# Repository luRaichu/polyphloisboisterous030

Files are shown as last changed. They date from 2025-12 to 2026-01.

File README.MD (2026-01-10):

# Polyphloisboisterous '030

This is my 16 MHz 68030 microprocessor upgrade board for Apple's Macintosh Plus, derived from the [reverse-engineered](https://github.com/alxlab-zone66x/Performer-SE-PL-CL/tree/main) MicroMac Performer. It is designed for easy and low-cost assembly by hobbyists.

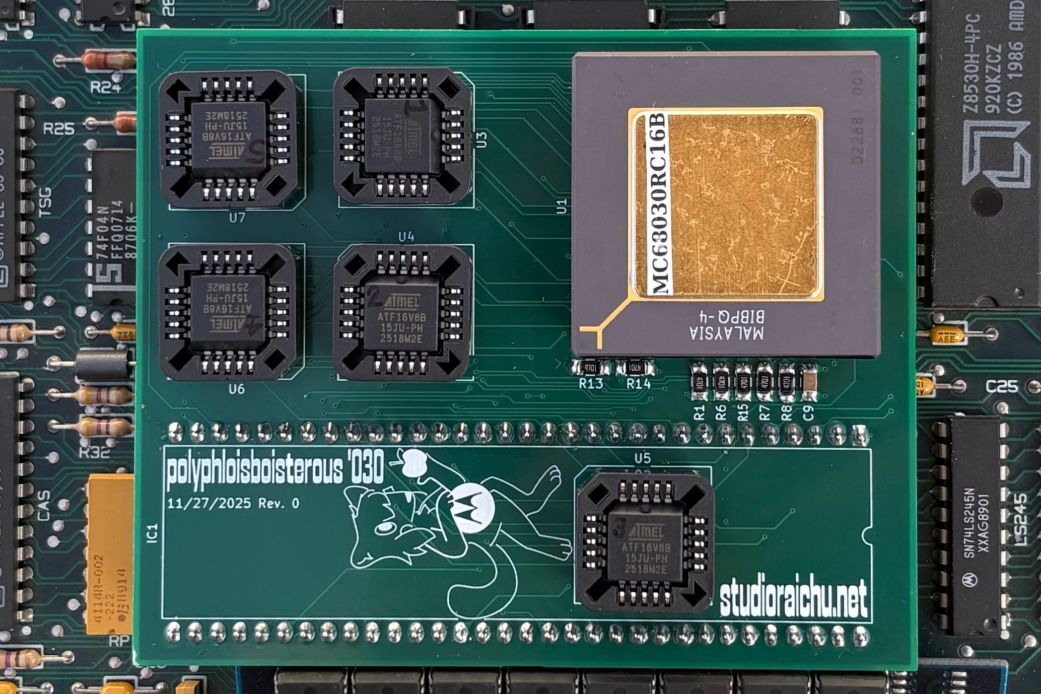
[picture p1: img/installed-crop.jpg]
Photo of Polyphloisboisterous '030 installed in Macintosh Plus


I created it because I didn't want to pay the relatively high manufacturing costs to get five Performer clone boards made, and I would have a hard time surface mount soldering the GALs.

My board is 50% smaller and 77% cheaper to manufacture over the original Performer, and doesn't use any dense SMD footprints. It can be assembled by anyone who can recap a vintage computer motherboard.

The provided PCB files are licensed under CC BY-NC-SA - they're NOT intended for commercial use.

## Notes on GALs

The original Performer GALs have been dumped. GAL16V8-15, PALCE16V8-15, and ATF16V8-15 have been tested as suitable replacements.

I used ATF16V8B-15JU, they are in stock at DigiKey and Mouser.

Faster/slower chips haven't been tested so far.

I used [afterburner](https://github.com/ole00/afterburner) to program GALs cheaply.

## Why is the FPU missing?

Because it's seldomly used on the Macintosh, and the PCB layout is simpler without it. There's not much point in having super fast floating point math when very little software uses it and if it'll be bottlenecked by the 16 MHz CPU and 16-bit data bus.

## Bill of Materials

|Quantity|Description|Designators|
|---|---|---|
|16|4.7 kΩ resistor, 1/4W or better, 1206 package|R1, R2, R3, R4, R5, R6, R7, R8, R9, R10, R11, R12, R13, R14, R15, R16|
|6|0.1μF ceramic capacitor, 6.3V or better, 1206 package|C4, C5, C6, C7, C8, C9|
|2|22μF tantalum capacitor, 10V or better, 2312 package|C1, C3|
|5|20 (4 x 5) pos. PLCC socket, through hole|U3, U4, U5, U6, U7|
|5|16V8 GALs or PALs, ATF16V8 recommended|U3, U4, U5, U6, U7|
|1|**Optional:** PGA-128 socket or equivalent for 68030. I used discrete machined pin headers|U1|
|1|MC68030, PGA, at least 16 MHz|U1|
||Headers and sockets to stack Polyphloisboisterous '030 on top of 68000. I used two 32 pos. round pin headers with a 64 (2 x 32) pos. machined pin DIP socket|IC1|

## Revision History
* 11/27/2025 Rev. 0 - First version
* 12/26/2025 Rev. 1 - Made board slightly shorter to help clear top of SIMM 1

## Assembly
1. Solder passives (resistors, capacitors) to board.

2. Solder GAL sockets to board.

3. Either solder PGA socket to board or permanently solder 68030 directly to board. In my case, I pushed individual pin headers onto the 68030 before soldering it. See [this graphic](img/cpuheaders-diagram.png) for my placement of these headers.

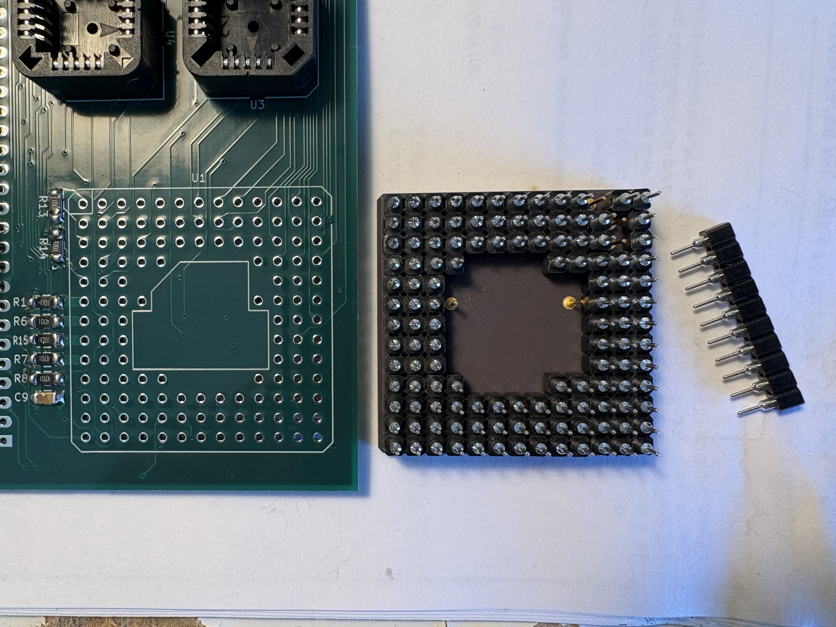
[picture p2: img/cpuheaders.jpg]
Photo of pin headers seated on 68030 pins


4. Solder 68000 piggyback connector(s) (i.e. male pin headers) to board.

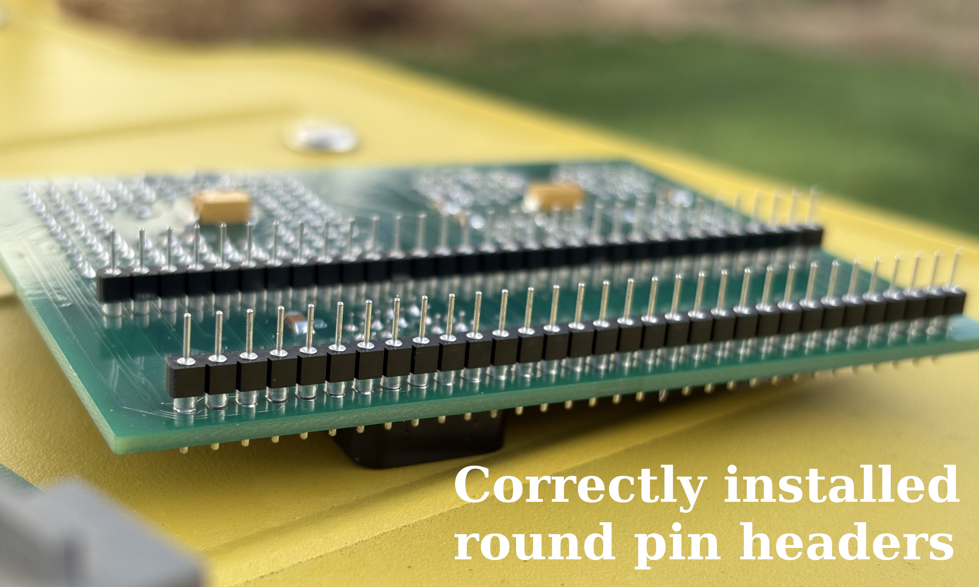
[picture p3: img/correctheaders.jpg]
Photo of correctly soldered male round pin headers


5. Program GALs and insert into sockets.

Your board should look like this:

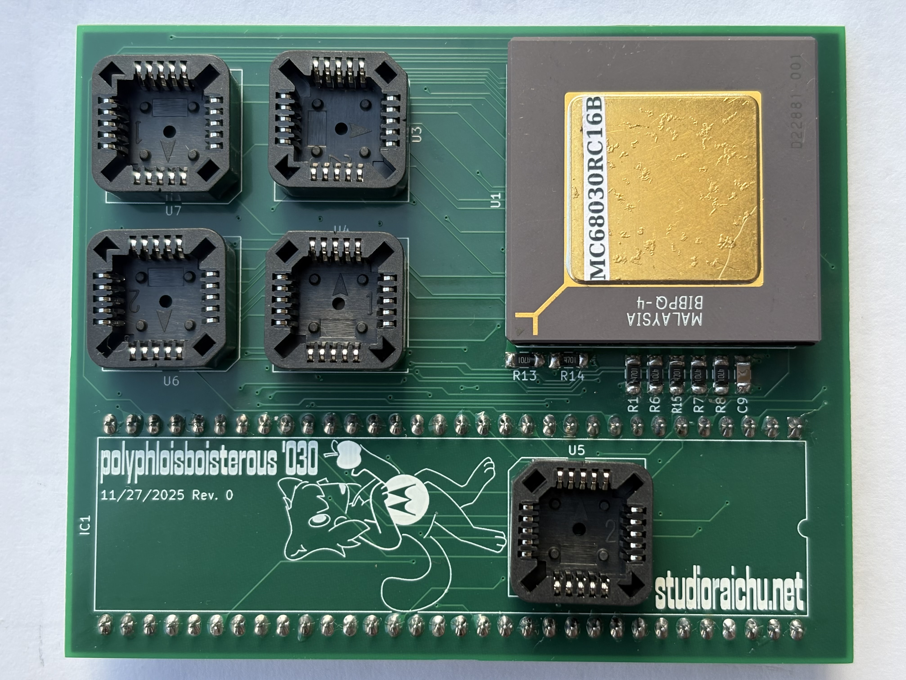
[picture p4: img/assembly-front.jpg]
Photo of assembled Polyphloisboisterous '030, front view


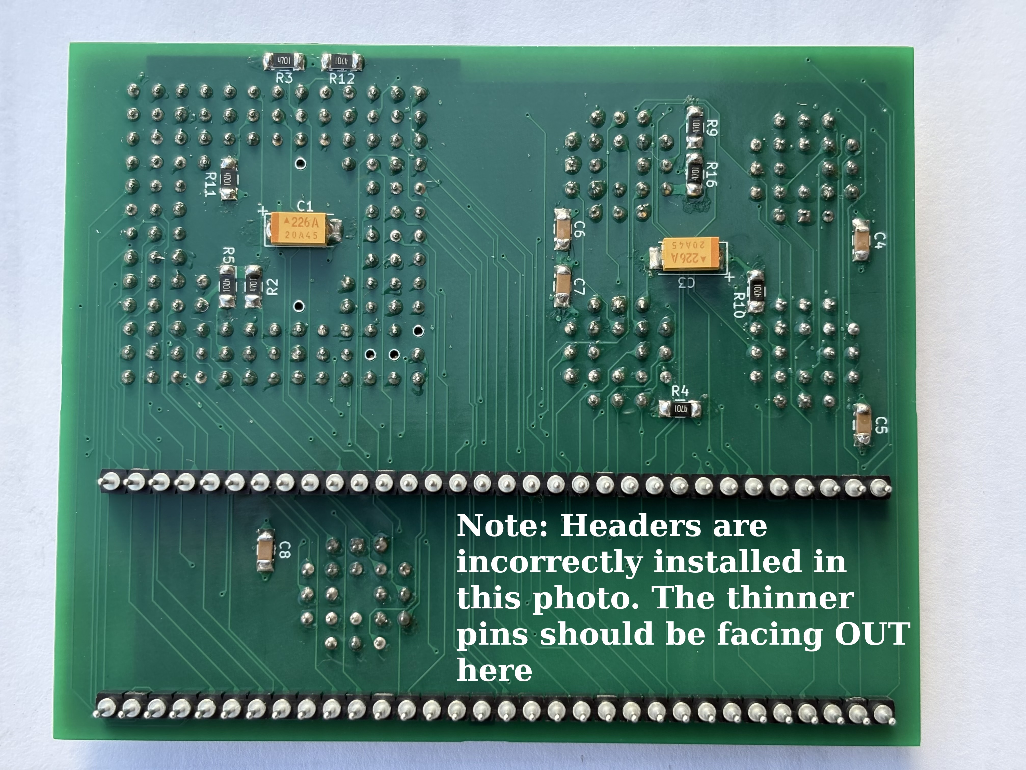
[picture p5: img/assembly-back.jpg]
Photo of assembled Polyphloisboisterous '030, back view


## Installation
1. Solder piggyback connector (i.e. female machined pin DIP socket) on top of the 68000 microprocessor on the Macintosh Plus logic board.

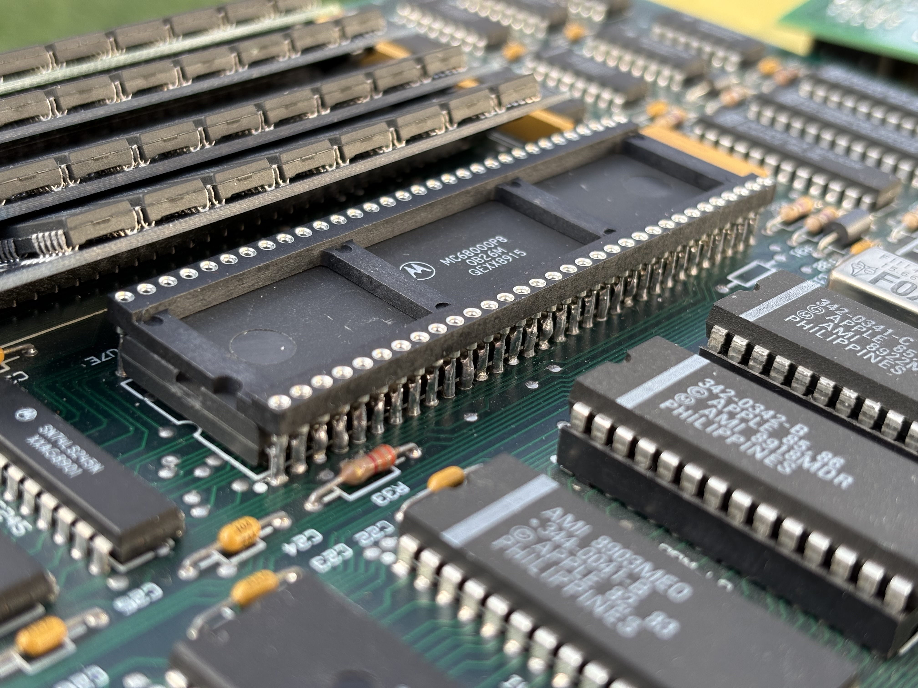
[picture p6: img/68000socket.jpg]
Photo of female machined pin DIP socket soldered on top of 68000


2. Seat the Polyphloisboisterous '030 accelerator on top of the 68000. It should look as pictured. Be mindful of the top of SIMM 1.

Photo of Polyphloisboisterous '030 installed on Macintosh Plus logic board, top view

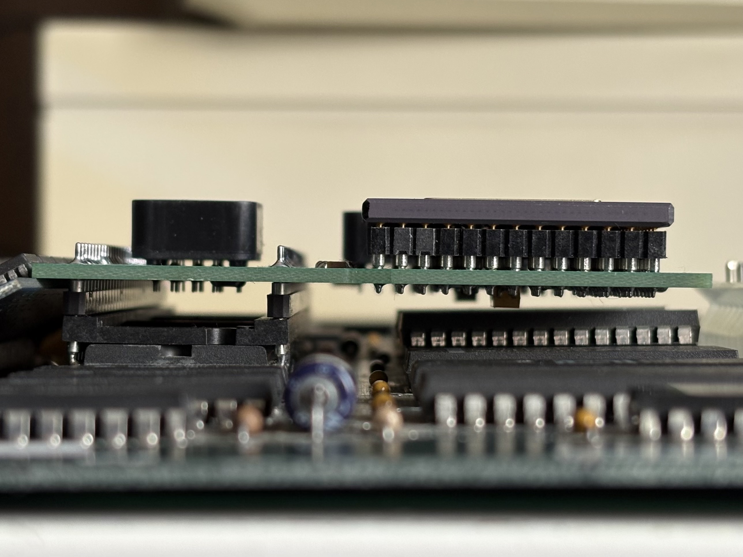
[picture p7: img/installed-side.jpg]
Photo of Polyphloisboisterous '030 installed on Macintosh Plus logic board, side view


3. Make a test: Have the logic board next to the Mac and connect the multicolored wire harness. Make sure that the logic board or accelerator do not touch any metal part of the chassis. Turn power on and listen for the beep. If you get a beep the accelerator is working. Turn power off and continue with the installation.

4. Carefully slide the logic board back into position while watching the accelerator **or** alternatively slide it **underneath** the rails and into the chassis, then slot the logic board into a rail on one side and bend the chassis on the other side in such a way that the logic board does go into the other rail as well.

5. Download the correct version of the [GemStart Universal](https://macintoshgarden.org/apps/accelerator-card-drivers) driver for your System Software. You will need:

    * GemStart 2.2 for System 6
    * GemStart 3.0 for System 7.0 (not recommended)
    * GemStart 7.1 for System 7.1

    If asked, identify your accelerator as a "Total Systems Mercury" in the installer (it is logically identical to this one). GemStart should show that you have a 16 MHz 68030.

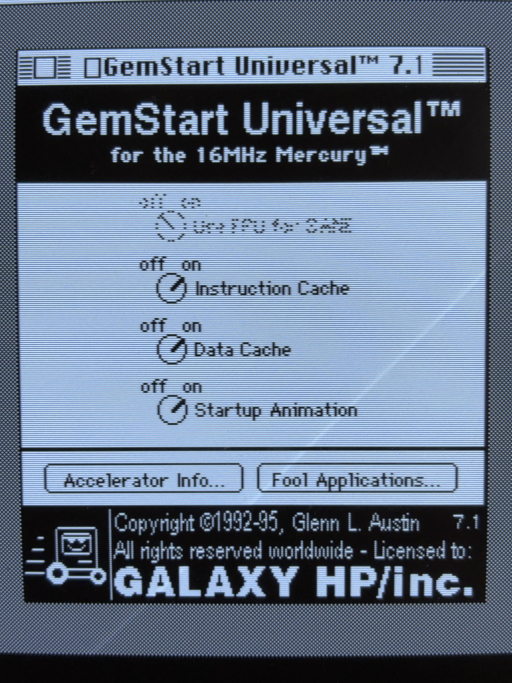
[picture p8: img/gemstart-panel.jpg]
Photo of GemStart control panel on screen


## Performance

I tested System 6.0.8 and 7.1 with this accelerator, both booted from my external BlueSCSI disk emulator.

Here are the benchmark results from Speedometer 3.23:

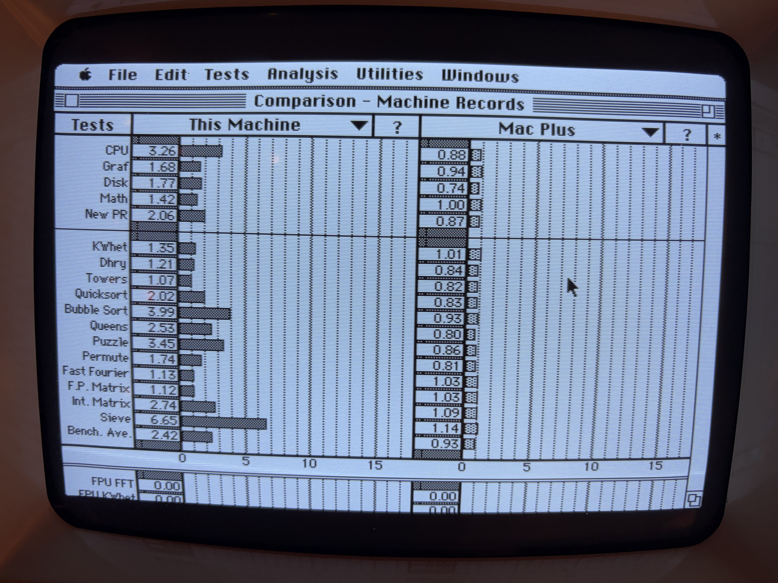
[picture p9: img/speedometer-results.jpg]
Photo of Speedometer 3.23 benchmark results on screen


To temporarily disable the Polyphloisboisterous '030 (and similar upgrades) using the Programmer's Switch, hold Interrupt after the boot chime then quickly press Reset. After the second chime release Interrupt. The upgrade is disabled until the next boot.

It appears that these accelerators affect the Macintosh's Sound Manager. Audio playback may be garbled or cut in and out rapidly. I don't know why.

## Thanks
To Bolle and Trash80toHP_Mini of 68kMLA forums, for reverse engineering the Mercury 030 and MicroMac Performer.

To alxlab-zone66x, for converting the Performer EAGLE files to a KiCad project.



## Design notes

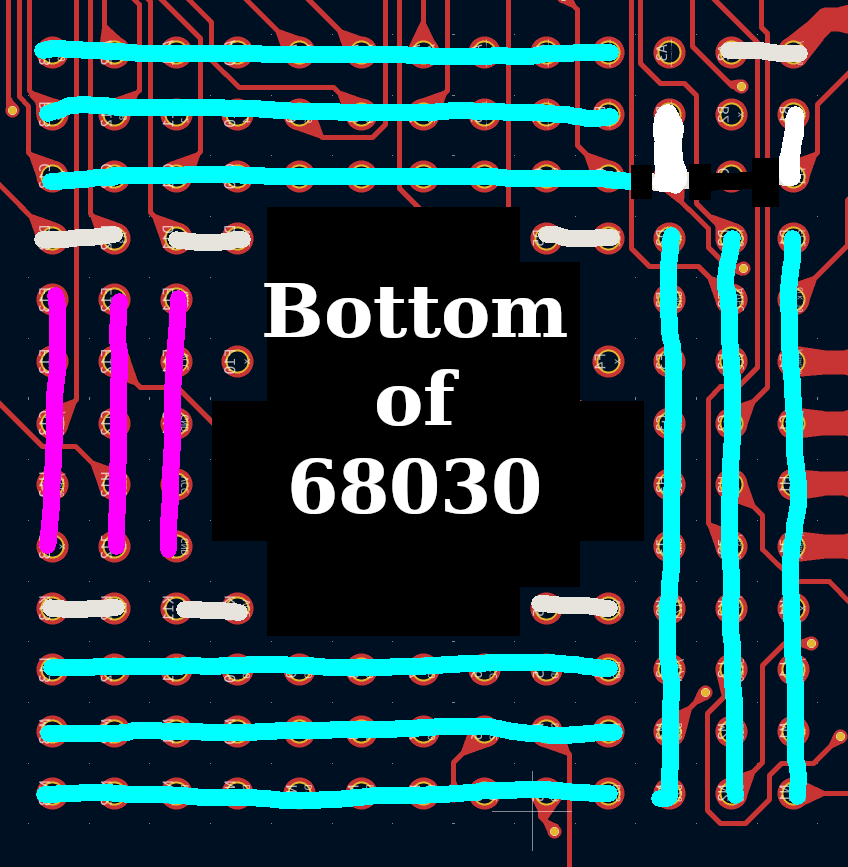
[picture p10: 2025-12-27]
img/cpuheaders-diagram.png

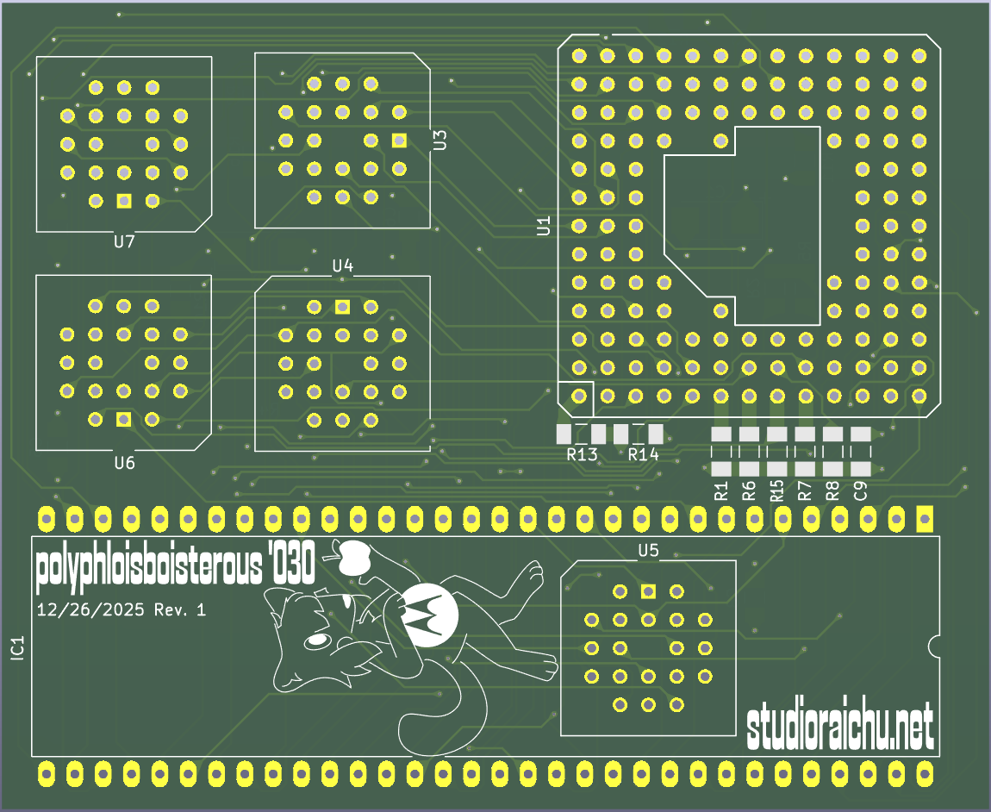
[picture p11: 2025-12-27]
kicad/polyphloisboisterous030-1.png

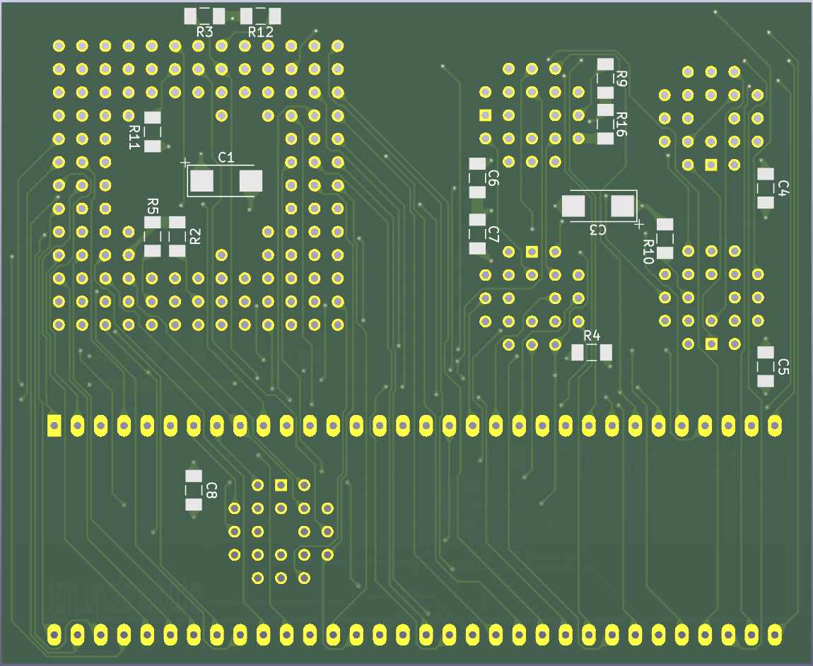
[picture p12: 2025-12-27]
kicad/polyphloisboisterous030-2.png

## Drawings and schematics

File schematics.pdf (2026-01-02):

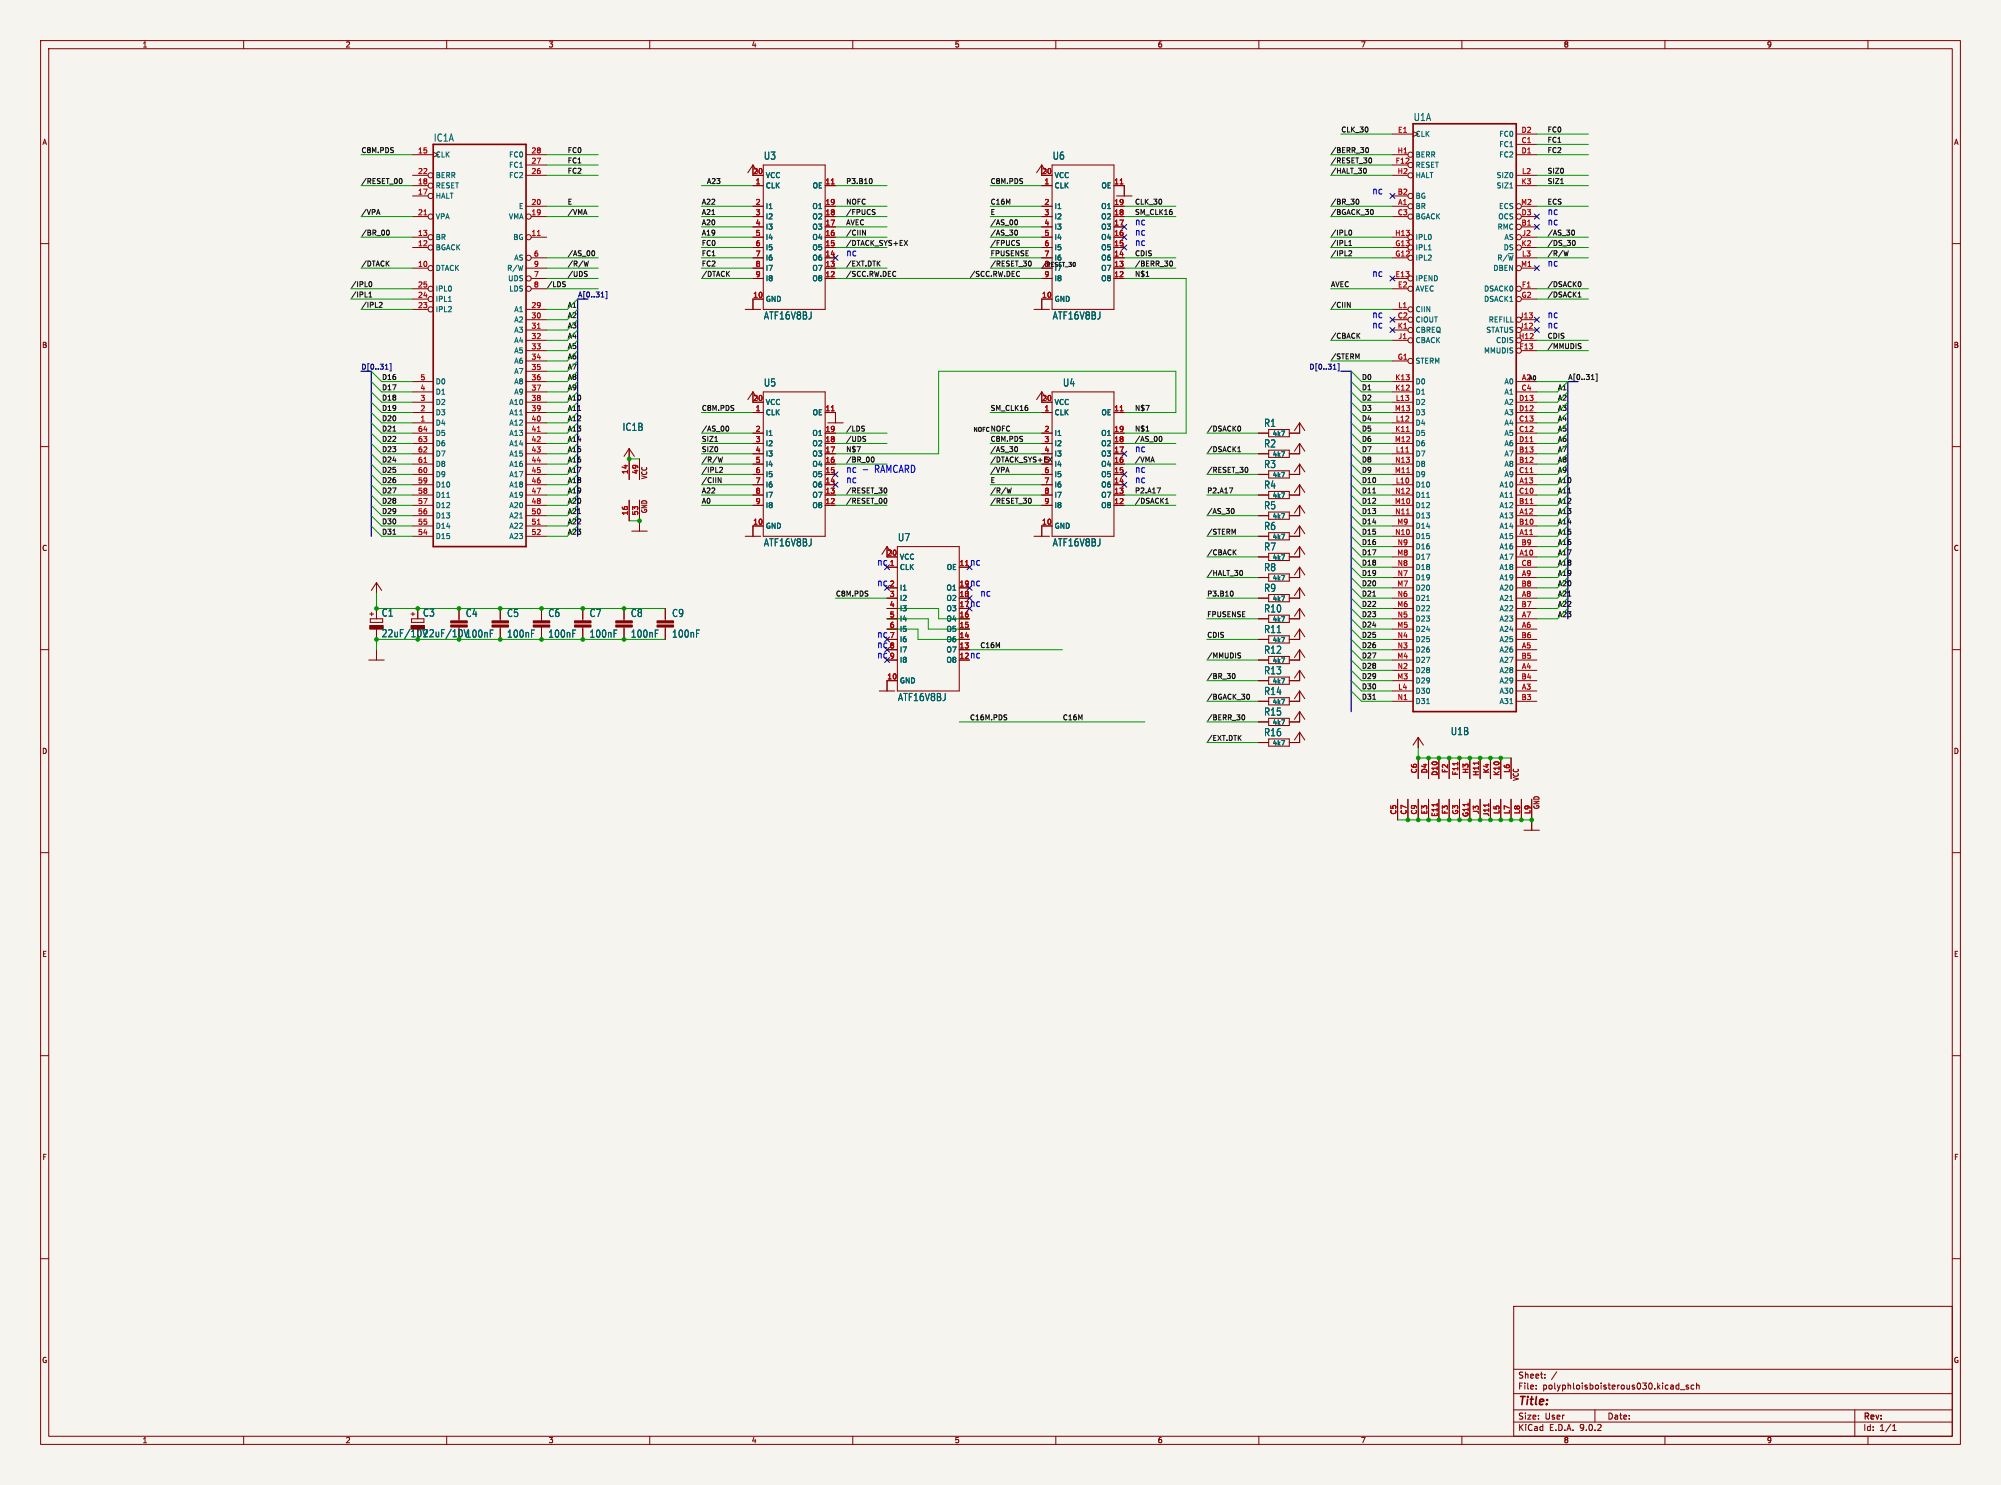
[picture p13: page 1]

CLK E1 BERR H1 RESET F12 HALT H2 BG B2 BR A1 BGACK C3
SIZ0 D31

IPEND E13 AVEC E2 CIIN L1 CIOUT C2 CBREQ K1 CBACK J1 STERM G1 D0 K13 D1 K12 D2 L13 D3 M13 D4 L12 D5 K11 D6 M12 D7 L11 D8 N13 D9 M11 D10 L10 D11 N12 D12 M10 D13 N11 D14 M9 D15 N10 D16 N9 D17 M8 D18 N8 D19 N7 D20 M7 D21 N6 D22 M6 D23 N5 D24 M5 D25 N4 D26 N3 D27 M4 D28 N2 D29 M3 D30 L4 D31 N1

Id: 1/1 Title: File: polyphloisboisterous030.kicad_sch Sheet: /

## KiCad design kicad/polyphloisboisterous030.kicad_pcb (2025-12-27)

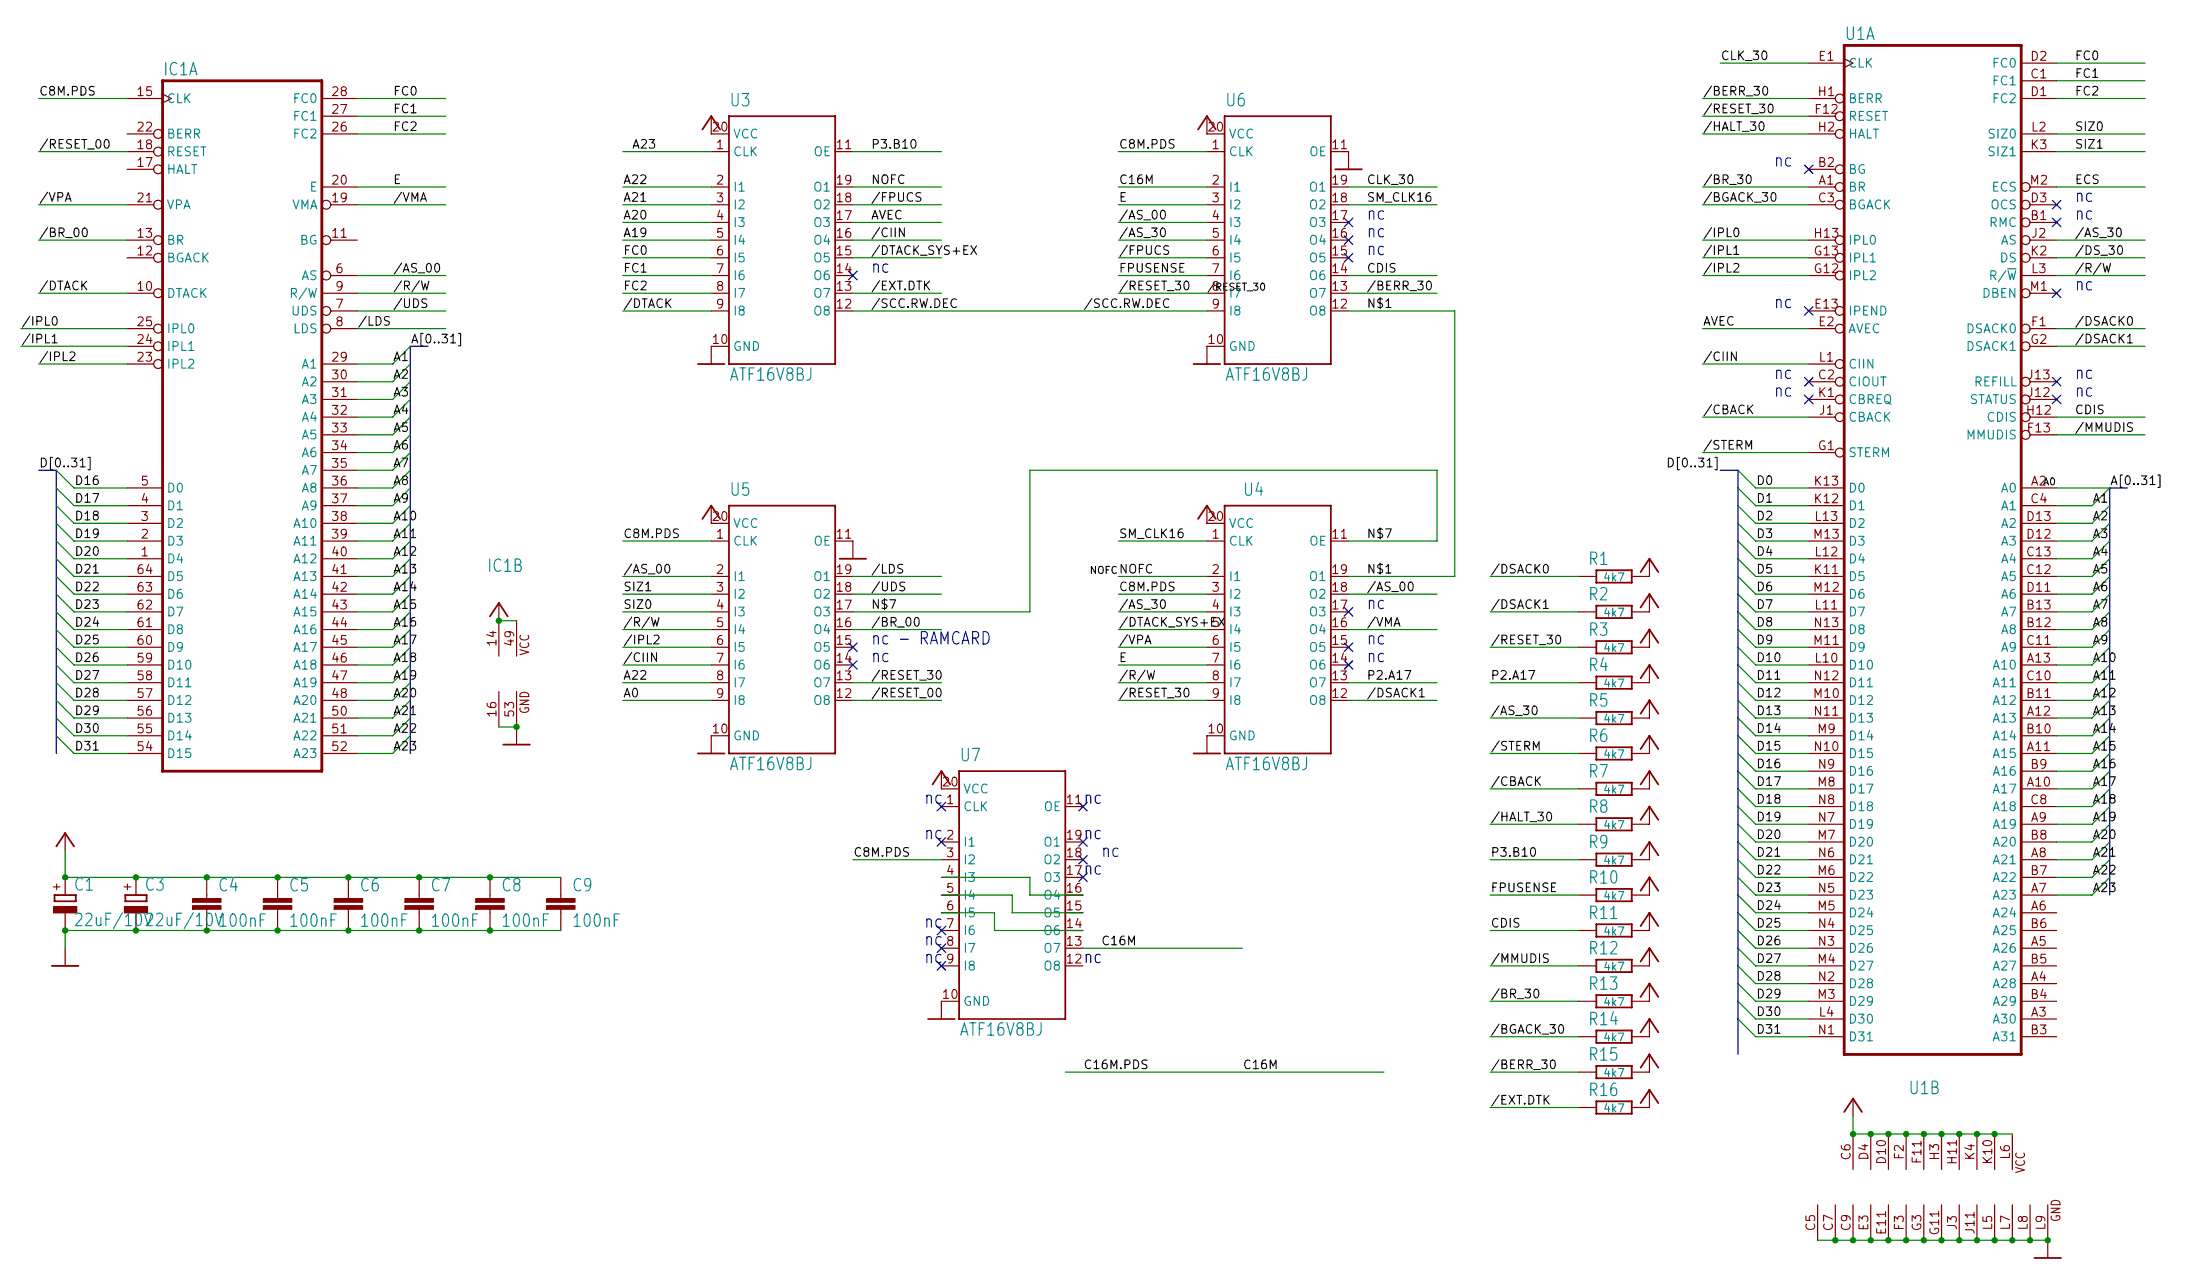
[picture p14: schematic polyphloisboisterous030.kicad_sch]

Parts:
C1, C3: 22uF/10V; CP_EIA-6032-15_Kemet-U_Pad2.25x2.35mm_HandSolder
C4, C5, C6, C7, C8, C9: 100nF; C_1206_3216Metric_Pad1.60x1.80mm_HandSolder
IC1: MC68000P; DIP-64_W22.86mm_LongPads_Mirror
R1, R2, R3, R4, R5, R6, R7, R8, R9, R10, R11, R12, R13, R14, R15, R16: 4k7; R_1206_3216Metric_Pad1.60x1.80mm_HandSolder
U1: MC68030RC; CPGA-128_Layout13x13_MC68030
U3, U4, U5, U6, U7: ATF16V8BJ; PLCC-20_THT-Socket

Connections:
/A0: U1.A2 (A0), U5.9 (I8)
/A1: IC1.29 (A1), U1.C4 (A1)
/A2: IC1.30 (A2), U1.D13 (A2)
/A3: IC1.31 (A3), U1.D12 (A3)
/A4: IC1.32 (A4), U1.C13 (A4)
/A5: IC1.33 (A5), U1.C12 (A5)
/A6: IC1.34 (A6), U1.D11 (A6)
/A7: IC1.35 (A7), U1.B13 (A7)
/A8: IC1.36 (A8), U1.B12 (A8)
/A9: IC1.37 (A9), U1.C11 (A9)
/A10: IC1.38 (A10), U1.A13 (A10)
/A11: IC1.39 (A11), U1.C10 (A11)
/A12: IC1.40 (A12), U1.B11 (A12)
/A13: IC1.41 (A13), U1.A12 (A13)
/A14: IC1.42 (A14), U1.B10 (A14)
/A15: IC1.43 (A15), U1.A11 (A15)
/A16: IC1.44 (A16), U1.B9 (A16)
/A17: IC1.45 (A17), U1.A10 (A17)
/A18: IC1.46 (A18), U1.C8 (A18)
/A19: IC1.47 (A19), U1.A9 (A19), U3.5 (I4)
/A20: IC1.48 (A20), U1.B8 (A20), U3.4 (I3)
/A21: IC1.50 (A21), U1.A8 (A21), U3.3 (I2)
/A22: IC1.51 (A22), U1.B7 (A22), U3.2 (I1), U5.8 (I7)
/A23: IC1.52 (A23), U1.A7 (A23), U3.1 (CLK)
/AVEC: U1.E2 (AVEC), U3.17 (O3)
/C8M.PDS: IC1.15 (CLK), U4.3 (I2), U5.1 (CLK), U6.1 (CLK), U7.3 (I2)
/C16M: U6.2 (I1), U7.13 (O7)
/CDIS: R11.1, U1.H12 (CDIS), U6.14 (O6)
/CLK_30: U1.E1 (CLK), U6.19 (O1)
/D0: U1.K13 (D0)
/D1: U1.K12 (D1)
/D2: U1.L13 (D2)
/D3: U1.M13 (D3)
/D4: U1.L12 (D4)
/D5: U1.K11 (D5)
/D6: U1.M12 (D6)
/D7: U1.L11 (D7)
/D8: U1.N13 (D8)
/D9: U1.M11 (D9)
/D10: U1.L10 (D10)
/D11: U1.N12 (D11)
/D12: U1.M10 (D12)
/D13: U1.N11 (D13)
/D14: U1.M9 (D14)
/D15: U1.N10 (D15)
/D16: IC1.5 (D0), U1.N9 (D16)
/D17: IC1.4 (D1), U1.M8 (D17)
/D18: IC1.3 (D2), U1.N8 (D18)
/D19: IC1.2 (D3), U1.N7 (D19)
/D20: IC1.1 (D4), U1.M7 (D20)
/D21: IC1.64 (D5), U1.N6 (D21)
/D22: IC1.63 (D6), U1.M6 (D22)
/D23: IC1.62 (D7), U1.N5 (D23)
/D24: IC1.61 (D8), U1.M5 (D24)
/D25: IC1.60 (D9), U1.N4 (D25)
/D26: IC1.59 (D10), U1.N3 (D26)
/D27: IC1.58 (D11), U1.M4 (D27)
/D28: IC1.57 (D12), U1.N2 (D28)
/D29: IC1.56 (D13), U1.M3 (D29)
/D30: IC1.55 (D14), U1.L4 (D30)
/D31: IC1.54 (D15), U1.N1 (D31)
/E: IC1.20 (E), U4.7 (I6), U6.3 (I2)
/ECS: U1.M2 (ECS)
/FC0: IC1.28 (FC0), U1.D2 (FC0), U3.6 (I5)
/FC1: IC1.27 (FC1), U1.C1 (FC1), U3.7 (I6)
/FC2: IC1.26 (FC2), U1.D1 (FC2), U3.8 (I7)
/FPUSENSE: R10.1, U6.7 (I6)
/N$1: U4.19 (O1), U6.12 (O8)
/N$7: U4.11 (OE), U5.17 (O3)
/NOFC: U3.19 (O1), U4.2 (I1)
/P2.A17: R4.1, U4.13 (O7)
/P3.B10: R9.1, U3.11 (OE)
/SIZ0: U1.L2 (SIZ0), U5.4 (I3)
/SIZ1: U1.K3 (SIZ1), U5.3 (I2)
/SM_CLK16: U4.1 (CLK), U6.18 (O2)
//AS_00: IC1.6 (AS), U4.18 (O2), U5.2 (I1), U6.4 (I3)
//AS_30: R5.1, U1.J2 (AS), U4.4 (I3), U6.5 (I4)
//BERR_30: R15.1, U1.H1 (BERR), U6.13 (O7)
//BGACK_30: R14.1, U1.C3 (BGACK)
//BR_00: IC1.13 (BR), U5.16 (O4)
//BR_30: R13.1, U1.A1 (BR)
//CBACK: R7.1, U1.J1 (CBACK)
//CIIN: U1.L1 (CIIN), U3.16 (O4), U5.7 (I6)
//DSACK0: R1.1, U1.F1 (DSACK0)
//DSACK1: R2.1, U1.G2 (DSACK1), U4.12 (O8)
//DS_30: U1.K2 (DS)
//DTACK: IC1.10 (DTACK), U3.9 (I8)
//DTACK_SYS+EX: U3.15 (O5), U4.5 (I4)
//EXT.DTK: R16.1, U3.13 (O7)
//FPUCS: U3.18 (O2), U6.6 (I5)
//HALT_30: R8.1, U1.H2 (HALT)
//IPL0: IC1.25 (IPL0), U1.H13 (IPL0)
//IPL1: IC1.24 (IPL1), U1.G13 (IPL1)
//IPL2: IC1.23 (IPL2), U1.G12 (IPL2), U5.6 (I5)
//LDS: IC1.8 (LDS), U5.19 (O1)
//MMUDIS: R12.1, U1.F13 (MMUDIS)
//RESET_00: IC1.18 (RESET), U5.12 (O8)
//RESET_30: R3.1, U1.F12 (RESET), U4.9 (I8), U5.13 (O7), U6.8 (I7)
//R/W: IC1.9 (R/W), U1.L3 (R/~W), U4.8 (I7), U5.5 (I4)
//SCC.RW.DEC: U3.12 (O8), U6.9 (I8)
//STERM: R6.1, U1.G1 (STERM)
//UDS: IC1.7 (UDS), U5.18 (O2)
//VMA: IC1.19 (VMA), U4.16 (O4)
//VPA: IC1.21 (VPA), U4.6 (I5)
GND: C1.-, C3.-, C4.2, C5.2, C6.2, C7.2, C8.2, C9.2, IC1.16 (GND@1), IC1.53 (GND@2), U1.C5 (GND@1), U1.C7 (GND@2), U1.C9 (GND@3), U1.E3 (GND@4), U1.E11 (GND@5), U1.F3 (GND@6), U1.G3 (GND@7), U1.G11 (GND@8), U1.J3 (GND@9), U1.J11 (GND@10), U1.L5 (GND@11), U1.L7 (GND@12), U1.L8 (GND@13), U1.L9 (GND@14), U3.10 (GND), U4.10 (GND), U5.10 (GND), U5.11 (OE), U6.10 (GND), U6.11 (OE), U7.10 (GND)
unnamed: U7.4 (I3), U7.16 (O4)
unnamed: U7.5 (I4), U7.15 (O5)
unnamed: U7.6 (I5), U7.14 (O6)
VCC: C1.+, C3.+, C4.1, C5.1, C6.1, C7.1, C8.1, C9.1, IC1.14 (VCC@1), IC1.49 (VCC@2), R1.2, R2.2, R3.2, R4.2, R5.2, R6.2, R7.2, R8.2, R9.2, R10.2, R11.2, R12.2, R13.2, R14.2, R15.2, R16.2, U1.C6 (VCC@1), U1.D4 (VCC@2), U1.D10 (VCC@3), U1.F2 (VCC@4), U1.F11 (VCC@5), U1.H3 (VCC@6), U1.H11 (VCC@7), U1.K4 (VCC@8), U1.K10 (VCC@9), U1.L6 (VCC@10), U3.20 (VCC), U4.20 (VCC), U5.20 (VCC), U6.20 (VCC), U7.20 (VCC)

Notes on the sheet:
nc - RAMCARD

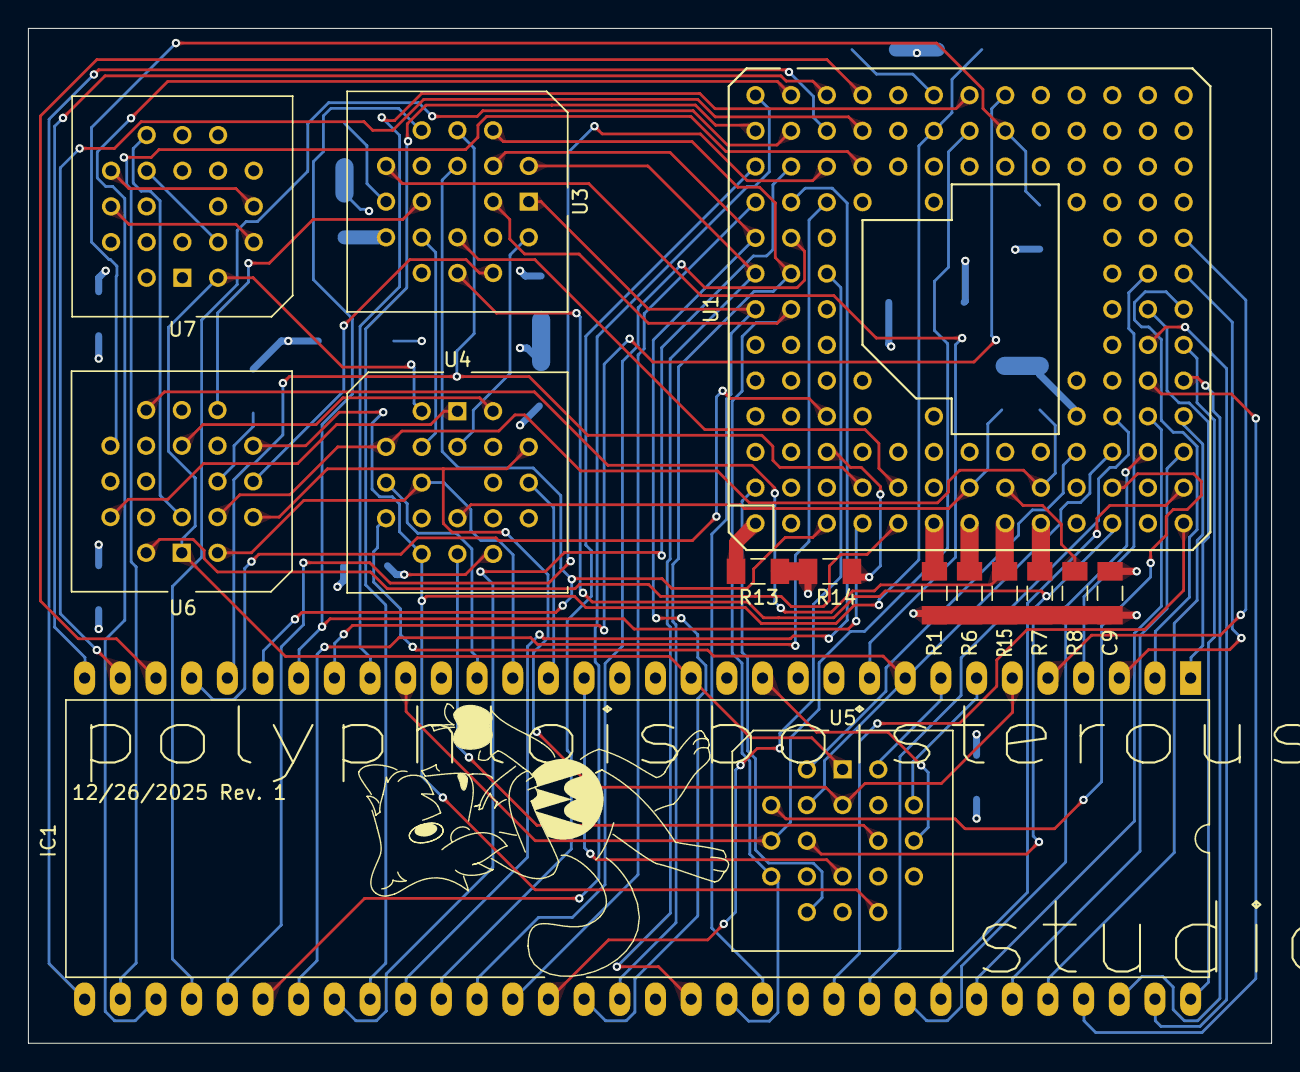
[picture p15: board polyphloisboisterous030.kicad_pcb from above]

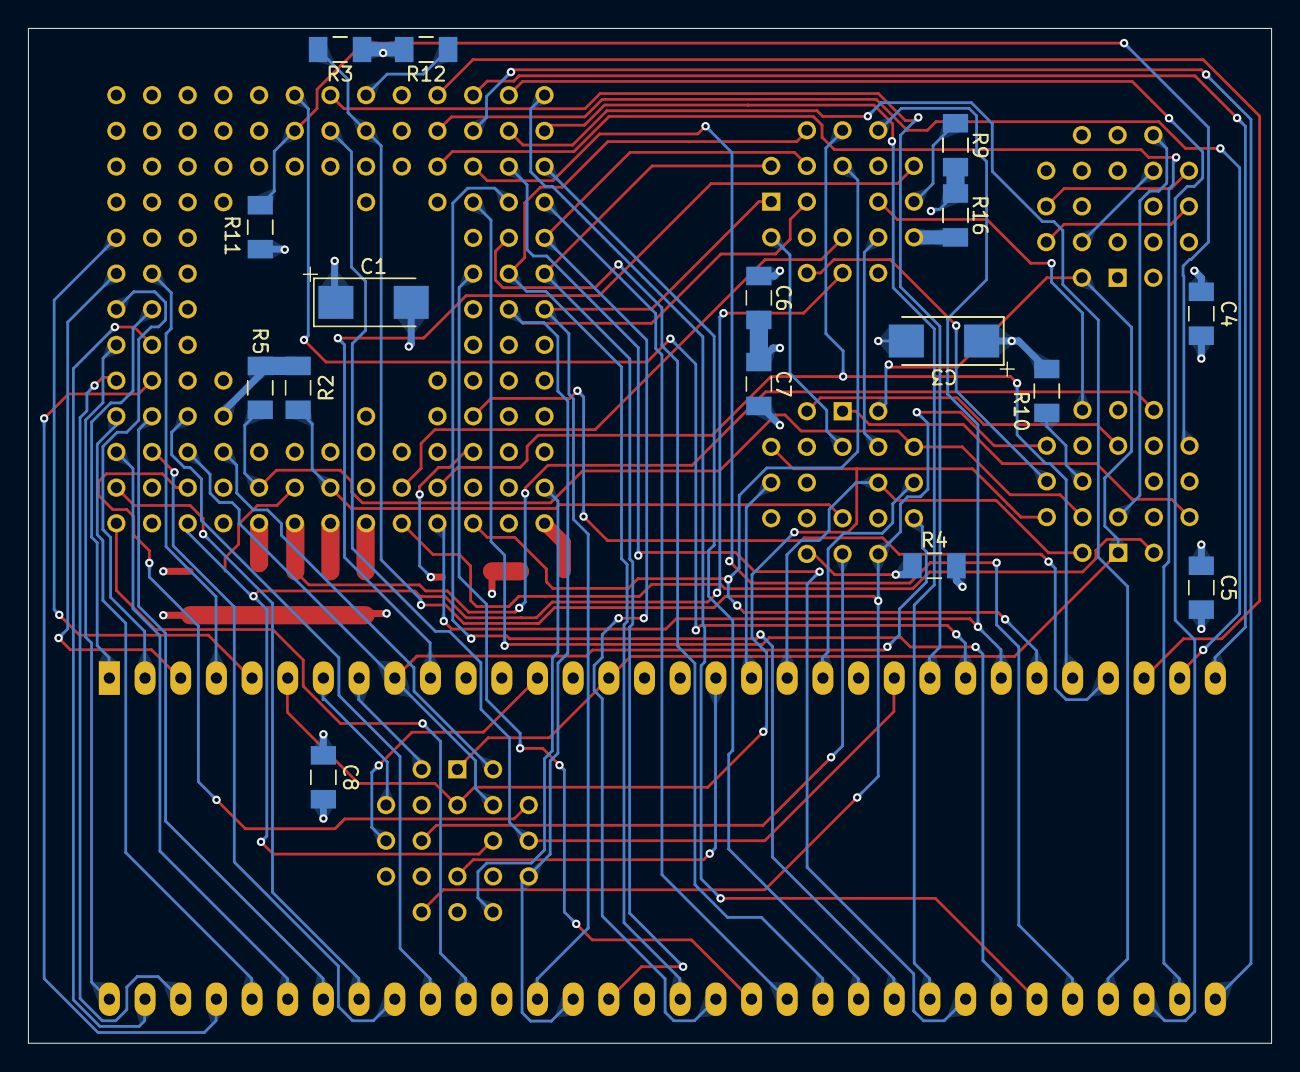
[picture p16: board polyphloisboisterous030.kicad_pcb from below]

Board: 4 copper layers, 88.5 x 72.2 mm, 31 parts (16 on the bottom side), 91 nets.

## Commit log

2025-12-27 add Polyphloisboisterous '030 files
    [MM Performer.sch, Performer-SE-PL-CL.kicad_pcb, Performer-SE-PL-CL.kicad_sch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]
2026-01-02 update README & add schematics pdf
